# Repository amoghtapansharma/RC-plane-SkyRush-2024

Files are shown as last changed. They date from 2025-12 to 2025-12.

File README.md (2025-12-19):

# RC-plane-SkyRush-2024
Participated in skyrush of  MIT Manipal
This repository contains the wireless control system code for the SkyRush 2024 RC aircraft. The system uses Arduino Nano microcontrollers and NRF24L01 wireless transceivers to transmit pilot control inputs from the ground transmitter to the onboard receiver, which controls the aircraft’s motor and control surfaces.

📡 System Overview

The control system is divided into two parts:

1. Transmitter (Ground Station)

Reads joystick and potentiometer inputs

Sends control data wirelessly using NRF24L01

2. Receiver (Aircraft)

Receives control data wirelessly

Controls:

Electronic Speed Controller (ESC)

Roll servo

Pitch servo

Yaw servo

Includes failsafe motor cut-off

🧩 Hardware Components
Transmitter Side

Arduino Nano

NRF24L01 module (with adapter board)

PS2 Joystick module

Potentiometers (Throttle / Yaw)

100 µF capacitor across NRF24L01 VCC–GND

Receiver Side

Arduino Nano

NRF24L01 module (with adapter board)

Brushless ESC

Brushless DC motor

Servo motors (Roll, Pitch, Yaw)

7.4 V Li-ion / Li-Po battery

⚠️ Important: NRF24L01 operates at 3.3 V only. Do NOT connect directly to 5 V.

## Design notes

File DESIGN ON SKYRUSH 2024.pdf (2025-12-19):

Design Report on SkyRush 2024 Team Name: EnergyGo
Team Id:- 13147
Date: 16/10/2024
Event: SkyRush 2024
1. Executive Summary
This design report provides the overall design, engineering, and flights designed for the RC aircraft that will be built for SkyRush 2024. Our approach to the design is to include high-flight stability, high maneuverability, and payload management with respect to the other safety and performance guidelines by the competition.
2. Design Overview
Our RC plane has a wingspan of precisely 1 m, with a central fuselage optimized for aerodynamic efficiency and is fitted with a payload bay structurally integrated to carry water. In terms of aircraft design, the primary objective of the aircraft will be to fulfill the needs of the competition-the mission of which would focus on stable flight, safety of payload, and navigation through waypoints.

2.1 Materials Used
We have achieved the structure with as little weight material without losing its structural strength. The important materials used include;

Balsa wood: Fuselage-to obtain a good strength-to-weight ratio
Carbon fiber: The added reinforcement for durability on the wing spars.
Depron foam: This is used for wing surfaces, and it achieves light weight together with a better rigid structure.
Epoxy and araldite: These are used to bond parts together securely.
2.2 Design Features
Wingspan: A wingspan of 1 meter ensures achieving maximum lift while being within the boundaries for a competition.

Fuselage: The streamlined section offers lesser drag and maximum speed during flight. Payload Bay: A centrally mounted, safety payload bay for the aircraft ensures stability in carrying water. The payload will not move when the aircraft is in flight.
Landing Gear: Three-fixed wheels were used for augmenting stability at take-off and landing times.
Propeller: A composite design for the propeller was selected since it had light strength.
3. Flight Characteristics
Our design focuses much on steady flight, which provides maneuverability to navigate the waypoints established in the mission path.

3.1 Takeoff and Landing
The aircraft is fixed-landing gear, which is facilitated to take off as well land on flat surface without much jerking. The grav center that ensured is also balanced without a high risk of nose-diving or tail-dragging in landing.

3.2 Maneuverability
We designed an optimized wing shape and size to provide good, stable, and controlled turns and easy flow over the predetermined path. The tail design, including the vertical stabilizer as well as the horizontal fins, helps in stability in terms of yaw and pitch adjustments.
4. Payload Management
An enclosed container holds the payload securely fastened in the payload bay, which is centrally located in the aircraft so that imbalance is held at a minimum. Shifting of payload is eliminated during flight because of the design of the bay, and the aircraft can be operated stably with and without the payload.
5. Power System
The motor uses a lightweight Li-Po battery that could have great power output while having relatively minimal weight in comparison to other types of batteries. The transmitter will also have a safety switch, which will be installed to cut off power to the motor to maintain compliance with safety requirements of the competition.

6. Safety Considerations
The aircraft has been created with an emphasis on the maximization of safety. Some of these include:

Safety inspection readiness: All structural elements and attachment have been found to undergo detailed tests to ensure that the plane complied with competition safety standards.
Controlled motor shutoff: An emergency cut-off switch operates the motor power by a tr

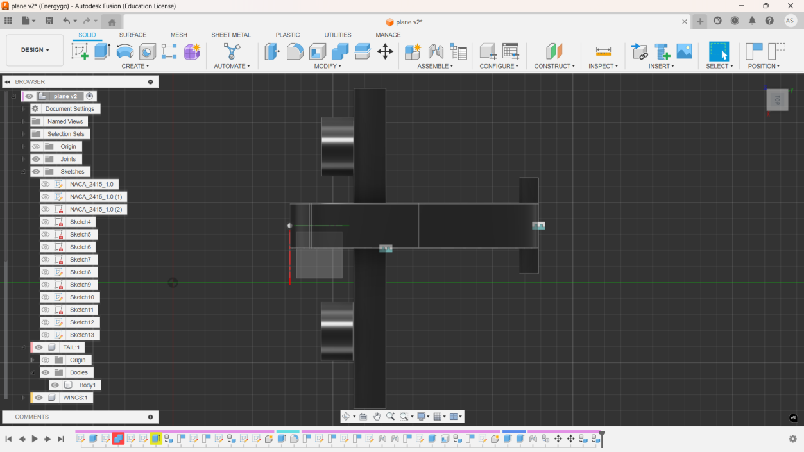
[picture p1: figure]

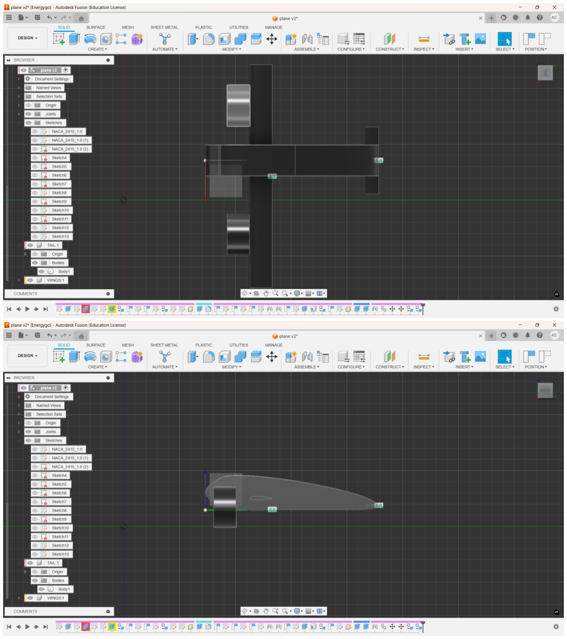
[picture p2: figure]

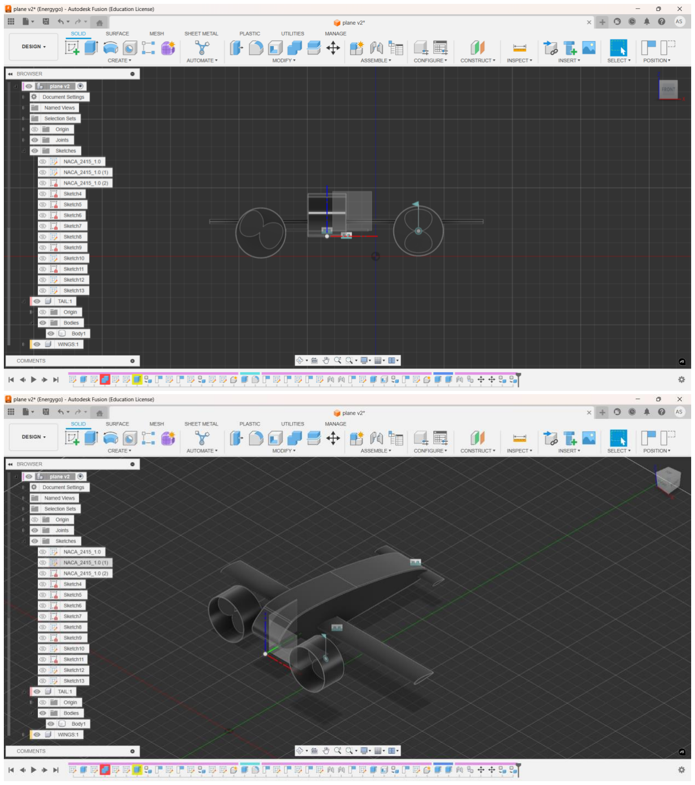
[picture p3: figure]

ansmitter switch.
Safe flight zone compliance: The control system of the plane has been set up so that the aircraft will safely operate within the specifically determined flight zones.

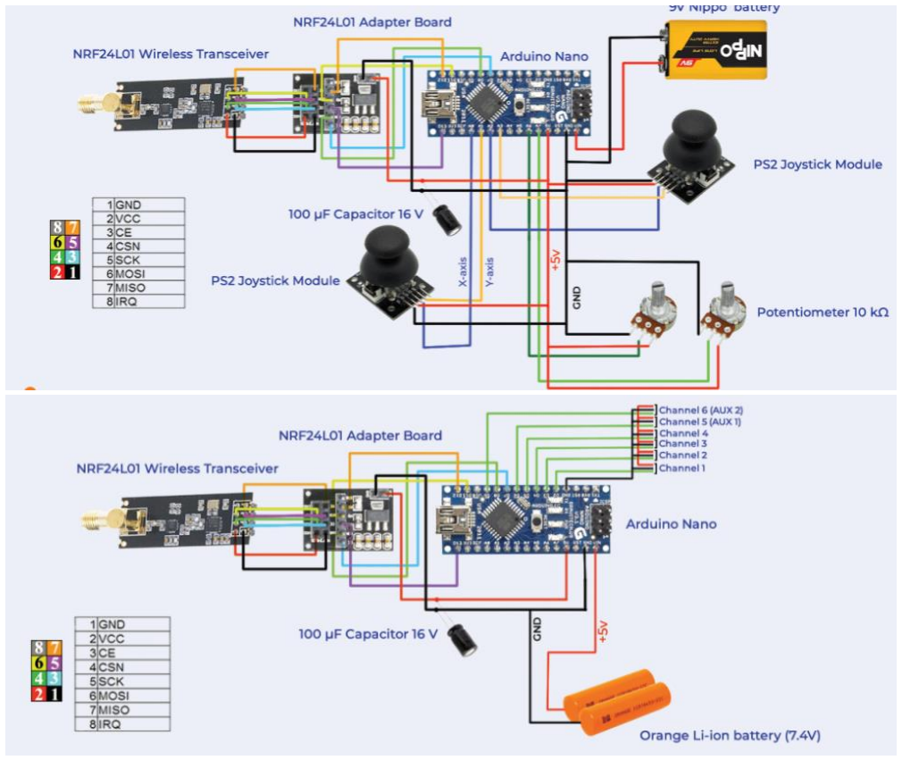
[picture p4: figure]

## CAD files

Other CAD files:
plane v1.f3d

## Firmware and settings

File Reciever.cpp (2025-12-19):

#include <SPI.h>
#include <nRF24L01.h>
#include <RF24.h>
#include <Servo.h>

RF24 radio(9, 10);   // CE, CSN
const byte address[6] = "SKY01";

Servo esc, servoRoll, servoPitch, servoYaw;

struct DataPacket {
  int roll;
  int pitch;
  int throttle;
  int yaw;
};

DataPacket data;

void setup() {
  esc.attach(3);
  servoRoll.attach(5);
  servoPitch.attach(6);
  servoYaw.attach(7);

  esc.writeMicroseconds(1000); // ESC arming
  delay(3000);

  radio.begin();
  radio.openReadingPipe(0, address);
  radio.setPALevel(RF24_PA_LOW);
  radio.setDataRate(RF24_250KBPS);
  radio.startListening();
}

void loop() {
  if (radio.available()) {
    radio.read(&data, sizeof(DataPacket));

    int throttle = map(data.throttle, 0, 1023, 1000, 2000);
    int roll     = map(data.roll, 0, 1023, 0, 180);
    int pitch    = map(data.pitch, 0, 1023, 0, 180);
    int yaw      = map(data.yaw, 0, 1023, 0, 180);

    esc.writeMicroseconds(throttle);
    servoRoll.write(roll);
    servoPitch.write(pitch);
    servoYaw.write(yaw);
  }
}

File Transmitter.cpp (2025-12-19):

#include <SPI.h>
#include <nRF24L01.h>
#include <RF24.h>

RF24 radio(9, 10);   // CE, CSN
const byte address[6] = "SKY01";

struct DataPacket {
  int roll;
  int pitch;
  int throttle;
  int yaw;
};

DataPacket data;

void setup() {
  radio.begin();
  radio.openWritingPipe(address);
  radio.setPALevel(RF24_PA_LOW);
  radio.setDataRate(RF24_250KBPS);
  radio.stopListening();
}

void loop() {
  data.roll     = analogRead(A0);  // Joystick X
  data.pitch    = analogRead(A1);  // Joystick Y
  data.throttle = analogRead(A2);  // Potentiometer
  data.yaw      = analogRead(A3);  // Optional

  radio.write(&data, sizeof(DataPacket));
  delay(20); // 50 Hz update
}
